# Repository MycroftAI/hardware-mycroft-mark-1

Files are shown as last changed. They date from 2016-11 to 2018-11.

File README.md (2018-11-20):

# hardware-mycroft-mark-1
*Open-sourcing our mechanical, electrical and industrial designs*

:sailboat: Note that this repository is a work-in-progress and will get better over time.

## Our open hardware principles
* **Copy our designs** – build your own Mycroft Mark 1 or its individual parts
* **Modify our designs** – remix is encouraged
* **Sell products based on our designs** – commercial use is permitted
* **Always keep the open license** – contribute your output back to the community
* **Credit the original author(s)** – like they do in science

## License
We're open-sourcing all our designs under the [CERN Open Hardware License](https://www.ohwr.org/licenses/cern-ohl/license_versions/v1.2), which is one of the open hardware licenses recommended by OSHWA, the Open Source Hardware Association. The release involves every single piece of our design except components we have no control over, like the Raspberry Pi. We've also joined the [Open Source Hardware Certification Program](http://www.oshwa.org/2016/10/07/announcing-the-oshwa-open-source-hardware-certification-program/).

OSHW

## Contact
If you are doing, or planning to do, something interesting with our designs, or if you just have a question regarding the files, get in touch with our Chief of Design Derick! (He was the one who designed Mycroft Mark 1’s enclosure.)

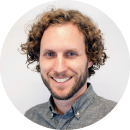
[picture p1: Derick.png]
Derick


**Derick Schweppe**  
Mycroft AI’s Chief of Design  
derick.schweppe@mycroft.ai

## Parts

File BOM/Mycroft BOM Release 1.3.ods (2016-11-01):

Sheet: Purchased Parts
Detailed list of off-the-shelf components in your product such as bateries, accessories, fasteners, etc.
Quantity | Part Number | Part Name | Description | Manufacturer | MPN | Unit Cost (USD) | Ext. Cost (USD)
1 | 3001 | Raspberry Pi 3 Model B | Raspberry Pi | Raspberry Pi Foundation | ??? | $33.750 | $33.750
1 | 3004 | hdmi cable-inside | 180-210 mm slim (3.5 mm outer diameter) male to panel mount female adpater | Vexos, see drawing: Mycroft 3004 HDMI male-female panel 1.11.pdf |  | $5.000 | $5.000
1 | 3009 | MicroSD Card (8gb) | SD card for software | Amazon |  | $2.430 | $2.430
1 | 3010 | Arduino Pro Mini 5v | Inland Arduino | Inland | 194126 | $4.000 | $4.000
1 | 3012 | Power Supply | 100-240VAC, 12.0VDC-15.0VDC, 18-24 Watts, UL approved | Mouser or equivalent with approval | 553-WSU120-1500 | $8.030 | $8.030
1 | 3013 | Speaker | HiWave BMR12 Compact 2" Full-Range Square Speaker 12W 8 Ohm | HiWave/Tectonic Elements (provided by Mycroft AI for first 1000 units) | 299-208 | $3.250 | $3.250
4 | 3002 | Housing Screws | m3x8mm thread forming screw | Stanley Delta PT M3x8mm | 96817A910 | $0.060 | $0.240
6 | 3003 | Speaker and Encoder Screws | m3x6mm thread forming screw | Stanley Delta PT M3x6mm | 96817A906 | $0.060 | $0.360
1 | 3005 | jst Mic Cable 1 | 180 mm 2 pin Female to Female JST XH connector cable 26 gauge | zhejiang leanhe electronics or equivalent with approval | ph-2y-180-ph-2y | $0.045 | $0.045
1 | 3006 | jst cable for front pcb | 180 mm 7 pin Female to Female JST XH connector cable 26 gauge | zhejiang leanhe electronics or equivalent with approval | xh-7y-180-xh-7y | $0.160 | $0.160
1 | 3008 | Rotary Encoder Cable | 200 mm 4 pin Female to Female JST XH Connector Cable 26 gauge | zhejiang leanhe electronics or equivalent with approval | xh-4y-180-xh-4y | $0.091 | $0.091
3 | 3011 | 18 mm standoffs | Raspberry Pi Standoffs | Essentra Components or equivalent with approval | RP914-ND | $0.179 | $0.537
1 | 3014 | speaker wire | 8.5" speaker wire with 2 pin JST XH connector and 22 gauge | zhejiang leanhe electronics or equivalent with approval | XH-2Y-200-free | $0.057 | $0.057
1 | 3016 | RCA mounting screw | #4 x 3/8 coarse thread plastic screw | Mcmaster-Carr | 97349A100 | $0.053 | $0.053
2 | 3017 | hdmi panel screws | M3x6mm thread forming screw | Stanley Delta PT M3x6mm | 91735A104 | $0.050 | $0.100
1 | 3018 | Serial Number and FCC label | label for Serial Number and FCC | Sticky Business |  | $0.230 | $0.230
1 | 3019 | ethernet cable |  | 6' ethernet cable |  | $0.500 | $0.500
1 | 3020 | rear 40 pin connector | 2.54mm PCB Socket Double Row Right Angle type | Dongguan Lanbo Electronics | PSRD254-40G-85 | $0.420 | $0.420
1 | 3021 | Raspberry Pi 40 pin connector | 2.54mm PCB Socket Double Row Female Header | Hello Electronics |  | $0.490 | $0.490
3 | 3022 | Arduino 12 pin Headers | 12 pin female connectors | Taojing Business (eBay purchase) |  | $0.020 | $0.060
1 |  | Freight |  |  |  | $6.000 | $6.000
 |  |  |  |  | TOTAL |  | $65.803

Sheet: Fabricated Parts
Detailed list of the custom fabricated parts in your product such as molded, stamped, diecast, etc.
Quantity | Part Number | Part Name | Description | Process Type | Material Type | Material Finish | Material Additives | Fixed Cost (USD) | Unit Cost (USD) | Ext. Cost (USD) | Notes
1 | 2001 | Housing Top | Housing Top | Injection Molding | ABS | bead blast | N/A | $20,000.000 | $2.200 | $2.200
1 | 2002 | Housing Bottom | Housing Bottom | Injection Molding | ABS | bead blast | N/A |  | $0.000 | $0.000
1 | 2003 | Expansion Plug R | Expansion Plug Right | Injection Molding | ABS | bead blast | N/A |  | $0.000 | $0.000
1 | 2004 | Expansion Plug L | Expansion Plug Left | Injection Molding | ABS | bead blast | N/A |  | $0.000 | $0.000
 | 2005 | knob | knob | Injection Molding | ABS | bead blast | N/A
1 | 2006 | Back Plate | Back Plate | Injection Molding | ABS | bead blast | N/A |  | $0.000 | $0.000
1 | 2007 | Front Plate | Front Plate | laser cutting | Acrylic / PMMA |  | N/A |  | $3.500 | $3.500
1 |  |  | Freight Injection molding |  |  |  |  |  | $0.500 | $0.500
1 |  |  | Freight Front Plate |  |  |  |  |  | $0.500 | $0.500
 |  |  |  |  |  |  |  |  | $0.000 | $0.000
 |  |  |  |  |  |  |  |  |  | $6.700

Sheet: PCBA
Detailed list of Bare Printed Circuit Boards onto which PCBA Components are added.
Quantity | Part Number | Part Name | Description | Material Type | Layer Count | Length (mm) | Width (mm) | Thickness (mm) | Min Trace Width | Min Trace Spacing | Min Device Pitch | Via Types | Mounting Types | Lead Time (wk) | MOQ | Fixed Cost (USD) | Unit Cost (USD) | Ext. Cost (USD) | Notes
1 | 1001 | Main_PCB | Main PCB | FR-4 | 2 |  |  | 1.60 | 6 mil | 6 mil |  | Through/Blind/Buried | SMT & THrough-Hole |  |  |  | $18.060 | $18.060
1 | 1002 | Front_PCB | Front PCB | FR-4 | 2 |  |  | 1.60 | 6 mil | 6 mil |  | Through/Blind/Buried | SMT & THrough-Hole |  |  |  | $18.460 | $18.460
1 | 1003 | Encoder_PCB | Encoder PCB | FR-4 | 2 |  |  | 1.60 | 6 mil | 6 mil |  | Through/Blind/Buried | SMT & THrough-Hole |  |  |  | $2.940 | $2.940
2 | 1004 | NeoPixel PCB | NeoPixel PCB | FR-4 | 2 |  |  | 1.60 | 6 mil | 6 mil |  | Through/Blind/Buried | SMT & THrough-Hole |  |  |  | $1.780 | $3.560
 |  |  |  |  |  |  |  |  |  |  |  |  |  |  |  |  |  | $0.000
 |  |  |  |  |  |  |  |  |  |  |  |  |  |  |  |  |  | $0.000
 |  |  |  |  |  |  |  |  |  |  |  |  |  |  |  | TOTAL | $43.020

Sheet: Packaging
Detailed list of all the elements of your product packaging.
Quantity | Part Number | Part Name | Description | Procurement Method | Lead Time (wk) | MOQ | Fixed Cost (USD) | Unit Cost (USD) | Ext. Cost (USD) | Notes
1 | PACK001 | Product Box | Printed Tablock Craft Cardboard Product Box 13"x10"x4" |  |  |  | $1,465.000 | $1.006 | $1.006
1 | PACK002 | Product Box Tape | Product Box Tape |  |  |  |  | $0.020 | $0.020
1 | PACK003 | Product Box Insert | folded cardboard tray |  |  |  |  | $1.000 | $1.000
1 | PACK004 | Product Bag | Protective Poly Bag |  |  |  |  | $0.200 | $0.200
1 | PACK005 | Quick Start Guide | Mulit-page Printed Manual |  |  |  |  | $1.000 | $1.000
1 | freight |  |  |  |  |  |  | $0.500 | $0.500
 |  |  |  |  |  |  |  | $0.000 | $0.000
 |  |  |  |  |  |  |  |  | $0.000
 |  |  |  |  |  |  |  |  | $0.000
 |  |  |  |  |  |  |  | $3.726 | $0.000
 |  |  |  |  |  |  |  |  | $0.000
 |  |  |  |  |  |  |  |  | $0.000
 |  | $1.006 per box for 1000 quantity |  |  |  |  |  |  | $0.000
 |  |  |  |  |  |  |  |  | $0.000
 |  | Fixed cost:
 |  | Die Cost: $854.00
 |  | Print Plate: $611.00

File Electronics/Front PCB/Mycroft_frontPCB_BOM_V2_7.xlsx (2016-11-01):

Description | Schem Ref | Qty | MFG Part # | Digikey # | x
0.1uf 0805 Captiro | FrontPCB C1, C2, C3, C9 | 4 | CL21F104ZBCNNNC | 1276-1007-1-ND | x
100uf Cap | FrontPCB C4, C5 | 2 | EEE-1VA101XP | PCE3951CT-ND | x
10uf 1210 CAP | FrontPCB C6, C8 | 2 | GMK325F106ZH-T | 587-1391-1-ND | x
2.2uf 0805 Cap | FrontPCB C7, C15 | 2 | C2012X7R1C225K125AB | 445-1420-1-ND | x
10nf 0805 Cap | FrontPCB C10 | 1 | C2012C0G1H103J060AA | 445-7519-1-ND | x
22uf 1210 Cap | FrontPCB C11, C12 | 2 | EMK325F226ZN-T | 587-1390-1-ND | x
3.9nf 0805 Cap | FrontPCB C13 | 1 | C0805C392K5RACTU | 399-1154-1-ND | x
Inductor 15uh | FrontPCB L1 | 1 | VLF10045T-150M3R5 | 445-3579-1-ND | x
JST XH 7pin | FrontPCB J1 | 1 | B7B-XH-A(LF)(SN) | 455-2252-nd
JST PH 2pin-RA | FrontPCB J3 | 1 | S2B-PH-K-S(LF)(SN) | 455-1719-ND
Mic | FrontPCB MK1 | 1 | CMA-4544PF-W | 102-1721-ND | x
220 ohm 0805 Resistor | FrontPCB R1-R16, R21-R36 | 32 | ERJ-6GEYJ221V | P220ACT-ND | x
10k 0805 Resistor | FrontPCB R18 | 1 | ERJ-6GEYJ103V | P10KACT-ND | x
100k 0805 Resistor | Frontpcb R17 | 1 | RC0805FR-07100KL | 311-100KCRCT-ND | x
45.3k 0805 Resistor | FronPCB R19 | 1 | ERJ-6ENF4532V | P45.3KCCT-ND | x
13k 0805 Resistor | FrontPCB R20 | 1 | ERJ-6GEYJ133V | P13KACT-ND | x
TSOP6238TR | FrontPCB U12 | 1 | TSOP6238TR | TSOP6238CT-ND | x
RT-8250 | FrontPCB U14 | 1 | RT8250GSP | 1028-1002-1-ND | x
AP2114 | FrontPCB U16 | 1 | AP2114H-3.3TRG1 | AP2114H-3.3TRG1DICT-ND | x
HT1632c | Front PCB U1 | 1 | HT1632c | NA | x
LED Matrix-GYX Optoelectronics | Front PCB U2, U3, U4, U5 | 4 | GYXM-788CW | NA | x

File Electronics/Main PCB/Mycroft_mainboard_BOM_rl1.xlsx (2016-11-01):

Description | Schem Ref | Qty per board | MFG Part # | Digikey #
18pf 0805 Cap | MB C1, C2, C7, C44, C45, C46, C47 | 7 | CL21C180JBANNNC | 1276-1107-1-ND
330uf Cap | MB C3, C4 | 2 | UWT1C331MNL1GS | 493-2180-1-ND
1nf 0805 Cap | MB C32, C37, C38, C39 | 4 | C2012X7R2E102K085AA | 445-2277-1-ND
10uf Cap | MB C6, C10, C11, C40 | 4 | T491A106K010AT | 399-3684-1-ND
100nf Cap 0805 | MB C8, C9, C12, C13 | 4 | CL21F104ZBCNNNC | 1276-1007-1-ND
0.1uf 0805 Cap | MB C14, C15, C16, C21, C31, C36, C48, C52, C53 | 9 | CL21F104ZBCNNNC | 1276-1007-1-ND
100uf Cap | MB C17, C18, C30, C35 | 4 | EEE-1VA101XP | PCE3951CT-ND
10uf 25v 1210 Cap | MB C19, C20 | 2 | GMK325F106ZH-T | 587-1391-1-ND
10nf 0805 Cap | MB C22, C54 | 2 | C2012C0G1H103J060AA | 445-7519-1-ND
22uf 1210 Cap | MB C23, C24, C55 | 3 | CL32A226KAJNNNE | 1276-1101-2-ND
3.9nf | MB C25 | 1 | C0805C392K5RACTU | 399-1154-1-ND
1uf 35v 0805 | MB C26, C27, C28, C29, C41 | 5 | C2012X5R1V105K085AB | 445-14415-1-ND
0.47uf 0805 | MB C33, C34, C51 | 3 | C0805C474K5RACTU | 399-8100-1-ND
10uf Can cap | MB C42, C43 | 2 | EEE-1EA100WR | PCE3895CT-ND
10uf 0805 Cap CER | MB C5 | 1 | CL21A106KPCLQNC | 1276-2402-1-ND
Polyfuse .5A 6v | MB F1 | 1 | 1206L050YR | F2112CT-ND
Polyfuse 8v 1.1a 1206 | MB F2 | 1 | 1206L110THYR | F3371CT-ND
Polyfuse 16v .25A 1206 | MB F3 | 1 | 1206L025YR | F2110CT-ND
FUSE PTC 0.75A 8V 1210 | MB F4 | 1 | 0ZCB0075FF2G | 507-1490-1-ND
FUSE PTC 1.5A 24V | MB F5 | 1 | MF-MSMF150/24X-2 | MF-MSMF150/24X-2CT-ND
Jst 7pin XH connector | MB J2 | 1 | B7B-XH-A(LF)(SN) | 455-2252-ND
Jst 4 pin xH connector | MB j3 | 1 | B4B-XH-A(LF)(SN) | 455-2249-ND
Rpi 2x20 connector | MB J4 | 1
2x20 output conenction | MB J6 | 1
10uf Inductor | MB L1 | 1 | NR4018T100M | 587-1664-1-ND
Ferrite bead | MB L2, L3, L6 | 3 | HI1812V101R-10 | 240-2543-1-ND
100 ohm resistor 0805 | MB R1, R2, R3, R30, R31, R32, R33, R36,R40, R41, R42, R43, | 14 | RC0805FR-07100RL | 311-100CRCT-ND
1k Resistor 0805 | MB R4, R5, R16, R9, R34, R35, R38, R39 | 8 | RC0805JR-071KL | 311-1.0KARCT-ND
47k Resistor 0805 | MB R6, R7, R10, R24, R25 | 5 | RMCF0805FT47K0 | RMCF0805FT47K0CT-ND
24k ohm 0805 Resistor | MB R8, | 1 | RC0805JR-0724KL | 311-24KARCT-ND
10 ohm 1206 Resistor | MB R11 | 1 | ERJ-8ENF10R0V | P10.0FCT-ND
100k 0805 Resistor | MB R12, R13, R17, R37, R46 | 5 | RC0805FR-07100KL | 311-100KCRCT-ND
10k 0805 Resistor | MB R14, R15, R18, R21, R26, R27 | 6 | ERJ-6GEYJ103V | P10KACT-ND
45.3k Resistor 0805 | MB R19 | 1 | ERJ-6ENF4532V | P45.3KCCT-ND
13k 0805 Resistor | MB R20 | 1 | ERJ-6GEYJ133V | P13KACT-ND
100 ohm 0805 Resistor | MB R22, R23 | 2 | ERJ-P06J101V | P100ADCT-ND
WM8731 Interface | MB U1 | 1 | WM8731SEDS/RV | WM8731SEDS/RVCT-ND
Tpa3113 | MB U2 | 1 | TPA3113D2PWPR | 296-25122-1-ND
2.1mm DC Jack | MB U12 | 1 | PJ-002A | CP-002A-ND
RCA Stereo Jack | MB U13 | 1 | RCJ-2123 | CP-1432-ND
RT-8250 | MB U14 | 1 | RT8250GSP | 1028-1002-1-ND
TXB0104 | MB U15, U28 | 2 | TXB0104DR | 296-21928-2-ND
12.288mhz crystal | MB Y1 | 1 | ABLS-12.288MHZ-B4-T | 535-10219-2-ND
Reverse polarity diode | MB D1 | 1 | PMEG4050EP,115 | 568-7408-1-ND
N channel fet level shift | MB Q1 | 1 | BSS138 | BSS138CT-ND
JST XH Speaker Con | MB J7 | 1 | B2B-XH-A(LF)(SN) | 455-2247-ND
inductor | MB L10 | 1 | VLF10045T-150M3R5 | 445-3579-1-ND
2.2uf 0805 capacitor | MB C49, C50 | 2 | LMK212B7225KG-T | 587-1286-1-ND
JST PH 2 pin | MB J8 | 1 | B2B-PH-K-S(LF)(SN) | 455-1704-ND
26 ohm ferrite bead 0603 | MB L4, L5 | 2 | BLM18KG260TN1D | 490-5252-1-ND
150k 0805 resistor | MB R44 | 1 | RMCF0805JT150K | RMCF0805JT150KCT-ND
2.2k 0805 resistor | MB R45 | 1 | RC0805JR-072K2L | 311-2.2KARCT-ND
Max9814 | MB U3 | 1 | MAX9814ETD+T | MAX9814ETD+TCT-ND
0805 Ferrite | L7, L8, L9 | 3 | 742792023 | 732-1613-1-ND

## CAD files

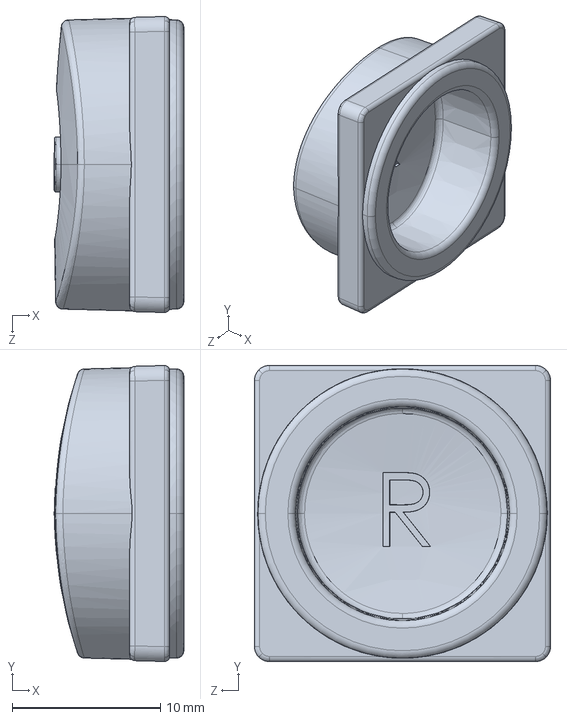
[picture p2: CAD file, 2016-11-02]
Plastics/3D print/expansion port right 1.21.STEP
8.75 x 20.0 x 20.0 mm

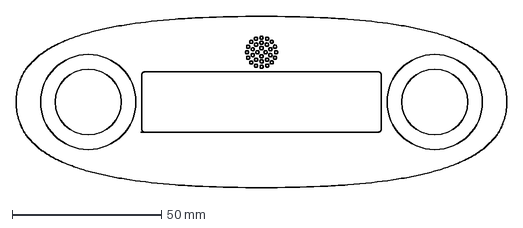
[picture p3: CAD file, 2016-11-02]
Plastics/Laser cut/Mycroft front plate cutting lines 1.21.dxf
164.4 x 57.4 mm

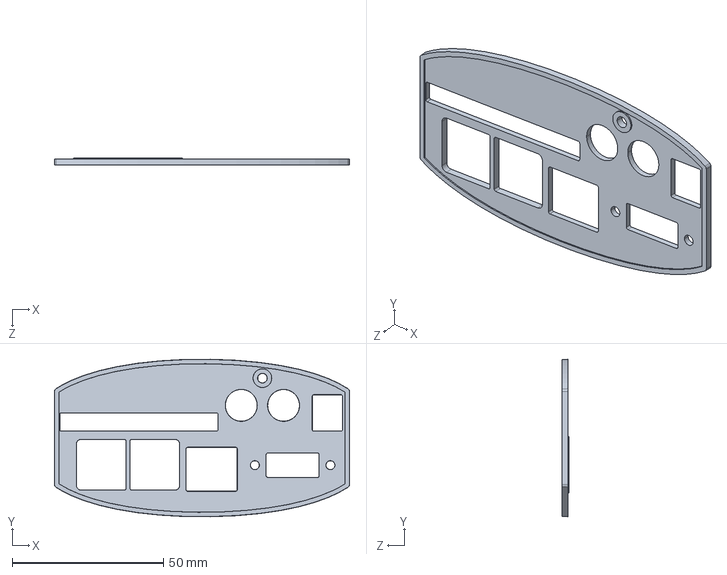
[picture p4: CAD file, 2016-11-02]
Plastics/3D print/back plate 1.21.STEP
97.6 x 52.1 x 2.40 mm

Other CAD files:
Plastics/3D print/expansion port left 1.21.STEP
Plastics/3D print/back plate 1.21.STL
Plastics/3D print/expansion port left 1.21.STL
Plastics/3D print/expansion port right 1.21.STL

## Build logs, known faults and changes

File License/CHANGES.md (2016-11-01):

Here we are compiling a community changelog. 

If you come up with a modification of our designs, please share it 
with the community, log your changes below, and upload the files to
our GitHub repository.

#Format

**Your name**  
*Date*  
Description of modification  

#Example

* older entry

* **David Smehlik**   
*12/31/2032*  
I used the original board design (electronics), but changed the 3D 
printed enclosure so Mark 1 has 3 feet instead of 4, and the face
and back plates are completely transparent. I created a pull request 
on GitHub with the modified files.

* newer entry

#Changelog

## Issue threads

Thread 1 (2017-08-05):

Use normal screws

singpolyma, 2017-08-05:
For future designs, consider using screws that users are likely to have a screwdriver for.

akuataja, 2018-04-23:
The team went back and forth on this. We eventually decided on Torx due to its advantages over the Phillips screws, some of which are mentioned [here](https://en.wikipedia.org/wiki/Torx#Principles_of_operation). As for the tool availability, I am told we include a Torx wrench in Mark I boxes. If you didn't get it in yours, send me a message, and I'll sort it out!

singpolyma, 2018-04-23:
I certainly didn't receive a driver with mine. Ended up buying a torx set (two, actually, first one wasn't long enough) so I could repair my Mark I

AFAICT torx screws are basically low-grade physical DRM equivalent for hardware

penrods, 2018-04-23:
The feedback is definitely appreciated.  As you noted, the depth/narrowness of the channel was also a challenge -- I own Torx drivers, but they were too wide to fit.  Torx do have some legit advantages -- I've never stripped out a Torx screw -- but they are not nearly as common.

As David mentioned, including a Torx driver is now done by default.  Once we realized this was an issue for many people we started including a "screwdriver" similar to what you get with Ikea furniture in the boxes.  We are happy to send one if you'd like, but for most of the early batches who have contacted us it is faster/easier to hit a local store rather than wait.

Sorry about the hassle, we are learning as we go on this!

kalon33, 2018-07-21:
@singpolyma same thing here, I didn't received a Torx wrench in my Mark I box and had to buy one today as my Mycroft won't boot and I had to try a microSD image restoring...

tiredoftry, 2018-09-11:
Looking for a driver for my screws as well.  It would be nice if the SD card was accessible without taking the Mark I apart.  Hopefully, this will be a feature on the Mark II.

ruth-connect, 2020-06-08:
Do you know what size Torx screwdriver you need for opening the Mark I please? The smallest screwdriver I have currently is a T15 - and that is too big.

Closed 2018-04-23.

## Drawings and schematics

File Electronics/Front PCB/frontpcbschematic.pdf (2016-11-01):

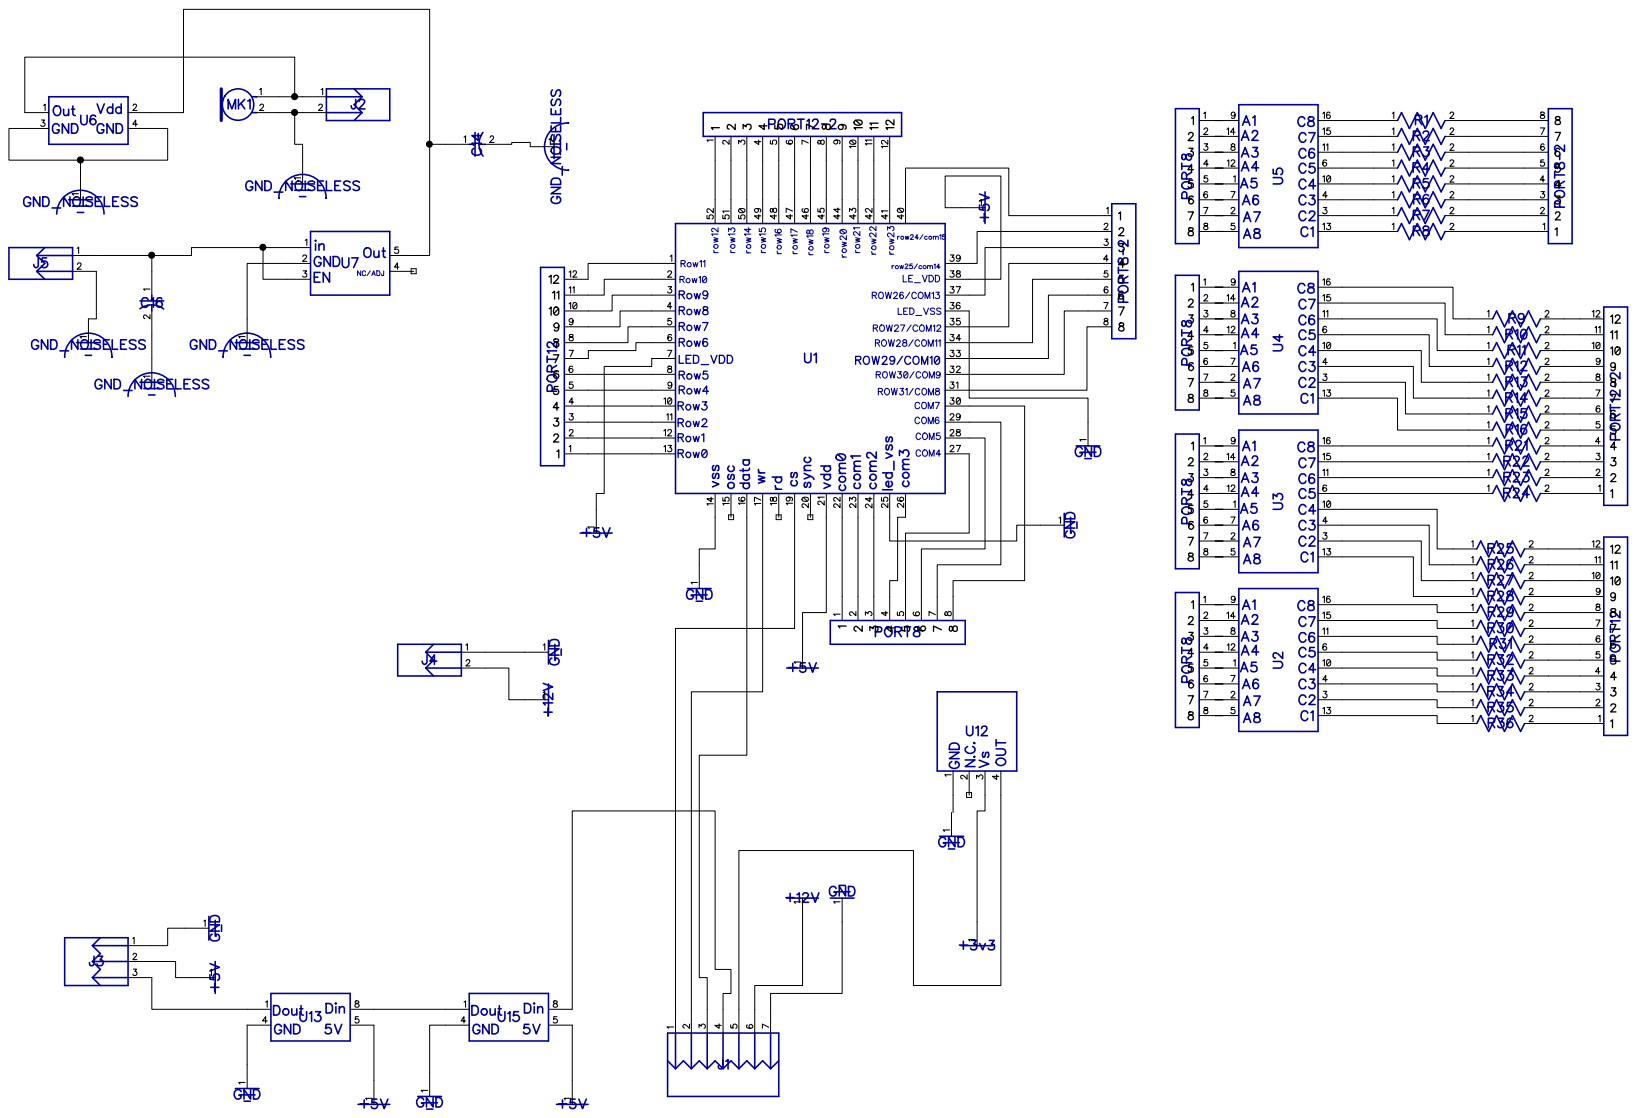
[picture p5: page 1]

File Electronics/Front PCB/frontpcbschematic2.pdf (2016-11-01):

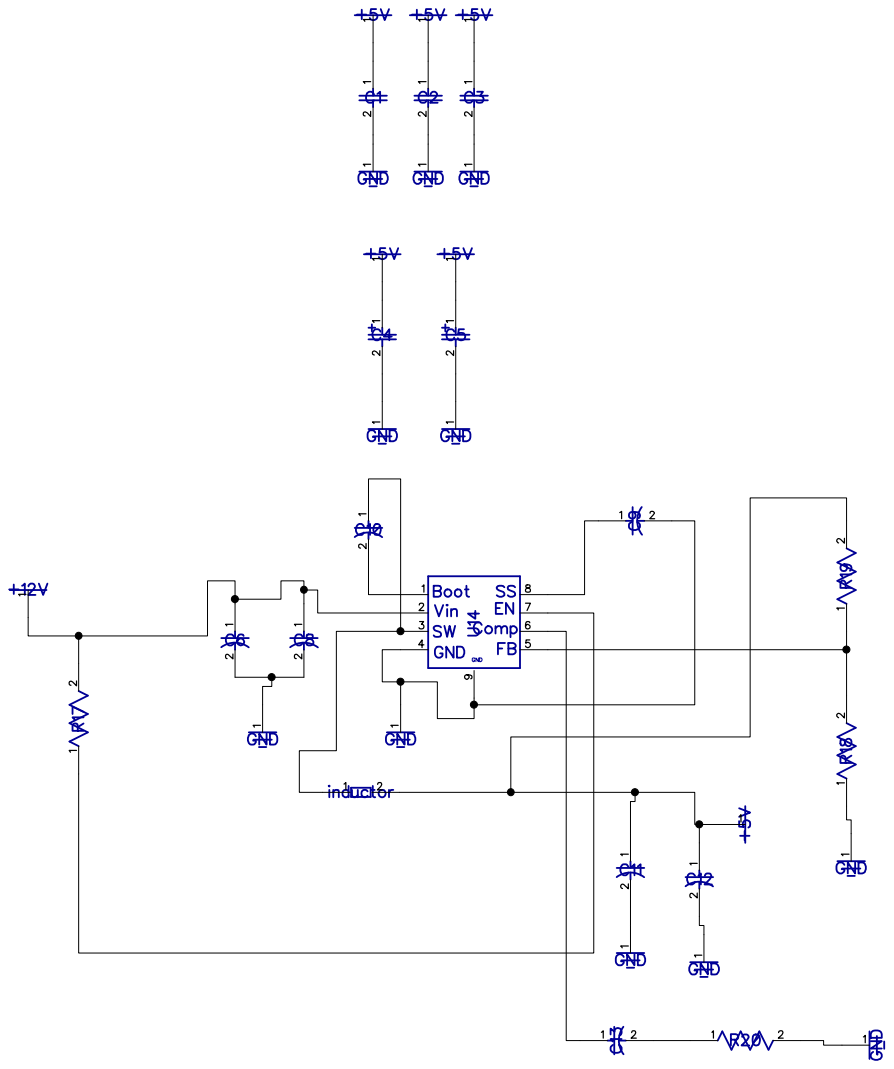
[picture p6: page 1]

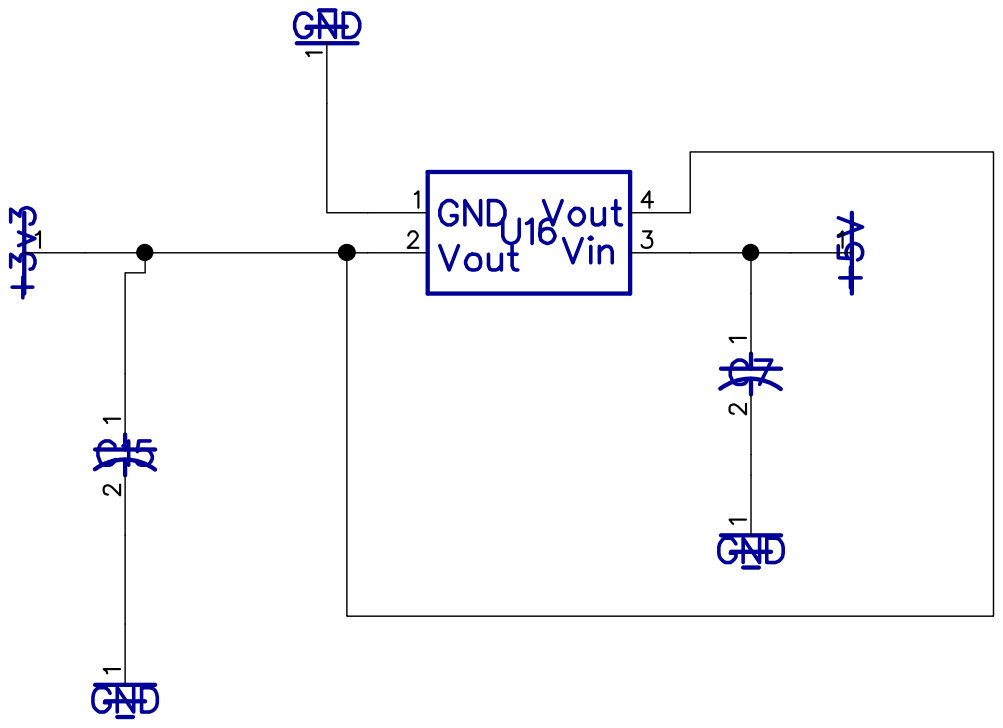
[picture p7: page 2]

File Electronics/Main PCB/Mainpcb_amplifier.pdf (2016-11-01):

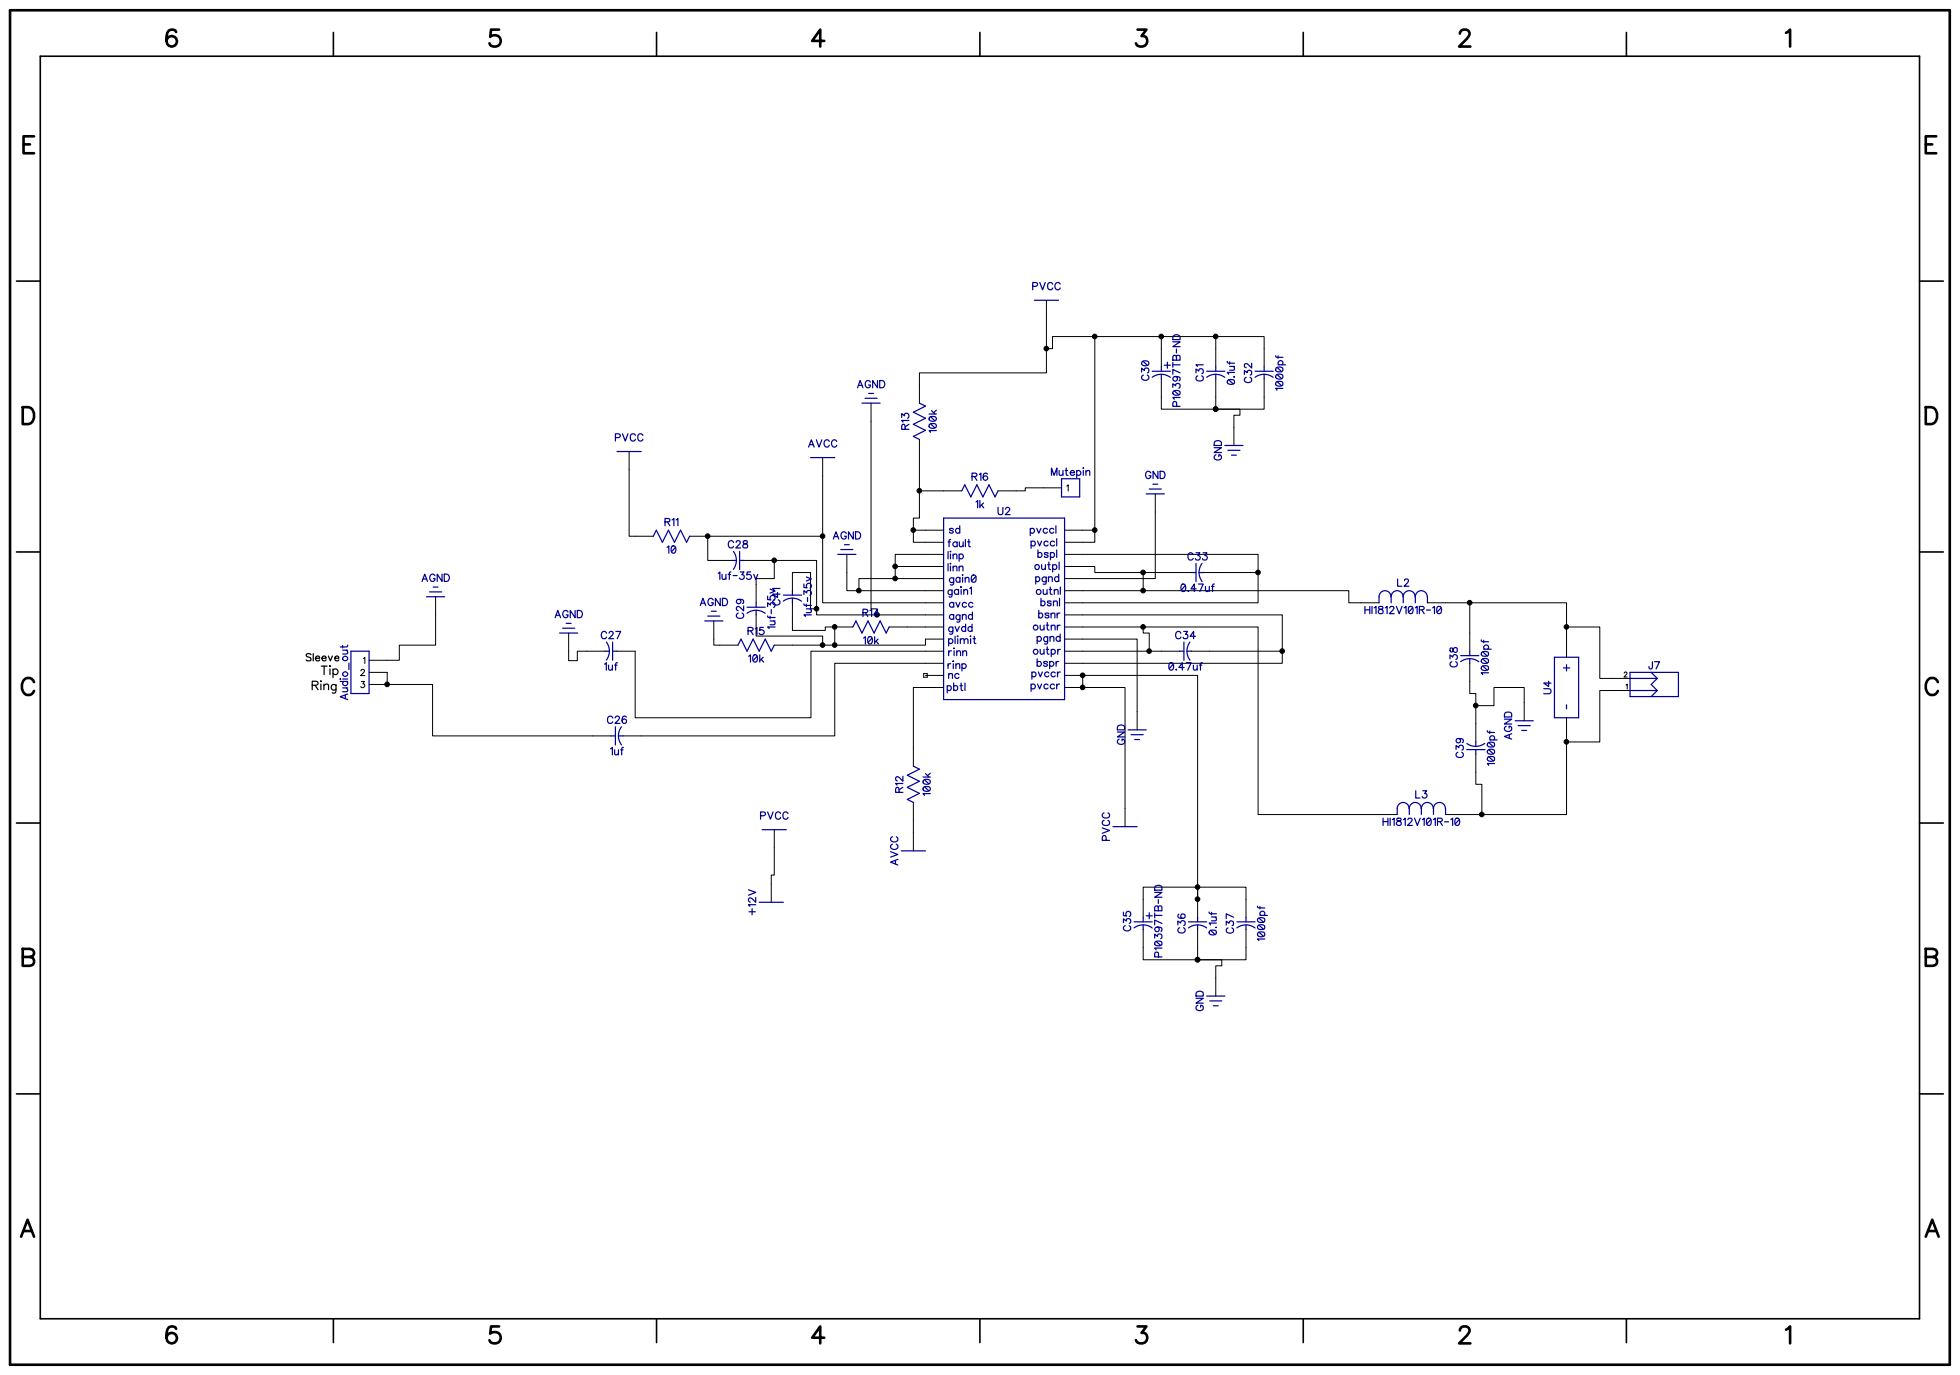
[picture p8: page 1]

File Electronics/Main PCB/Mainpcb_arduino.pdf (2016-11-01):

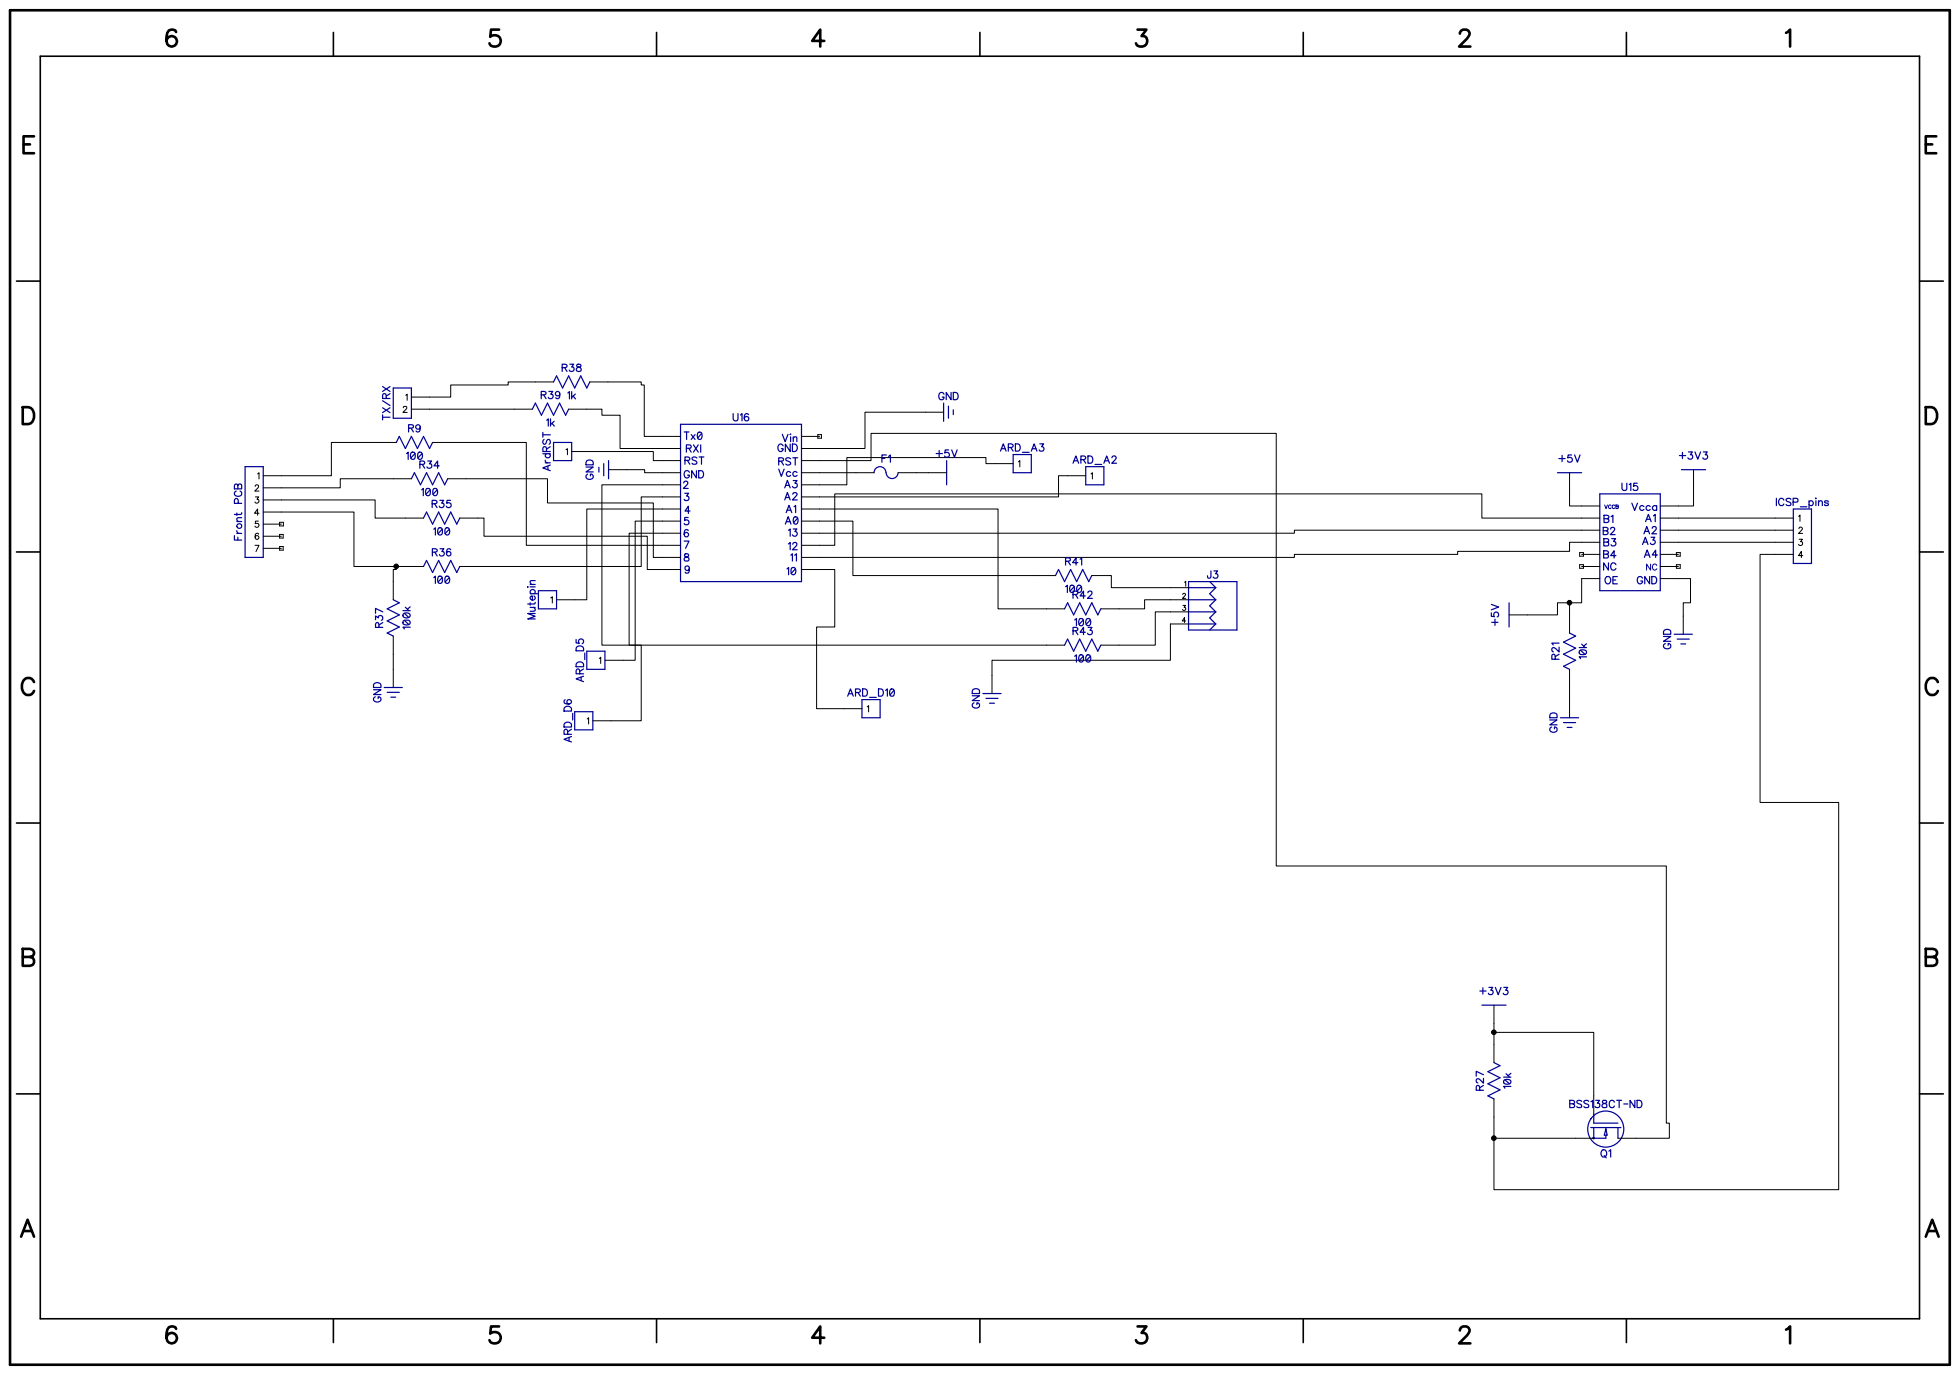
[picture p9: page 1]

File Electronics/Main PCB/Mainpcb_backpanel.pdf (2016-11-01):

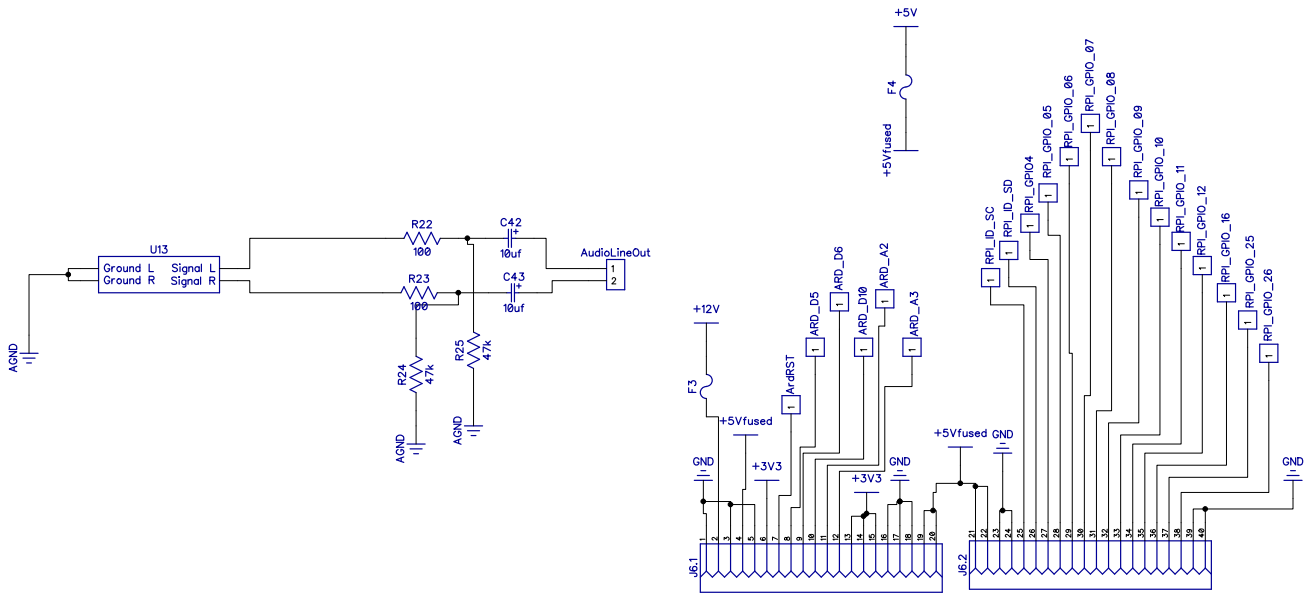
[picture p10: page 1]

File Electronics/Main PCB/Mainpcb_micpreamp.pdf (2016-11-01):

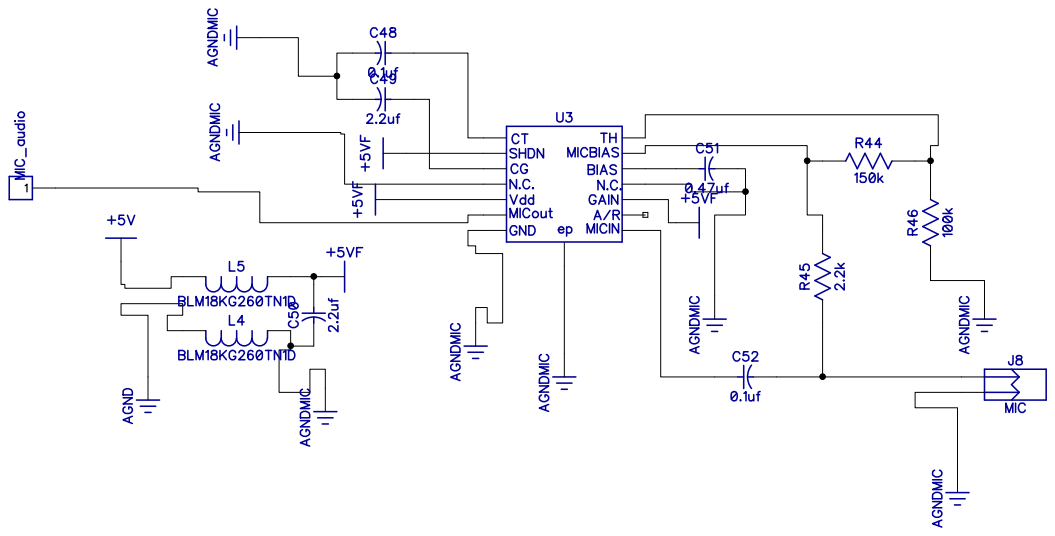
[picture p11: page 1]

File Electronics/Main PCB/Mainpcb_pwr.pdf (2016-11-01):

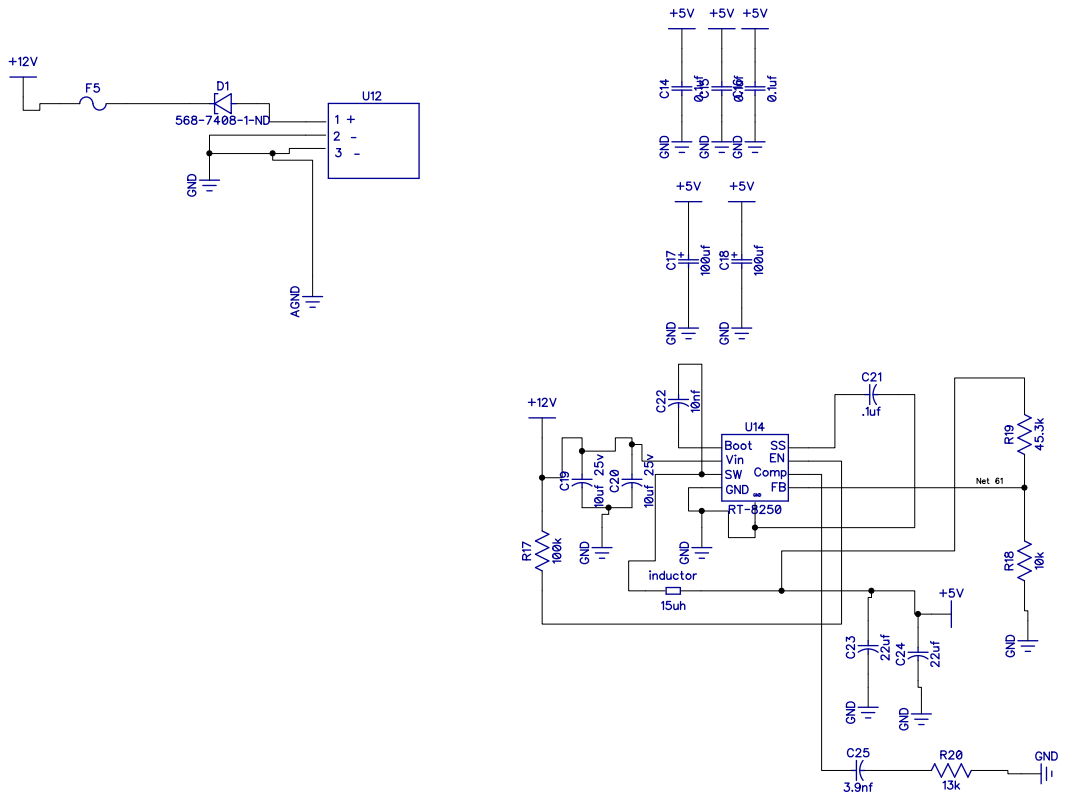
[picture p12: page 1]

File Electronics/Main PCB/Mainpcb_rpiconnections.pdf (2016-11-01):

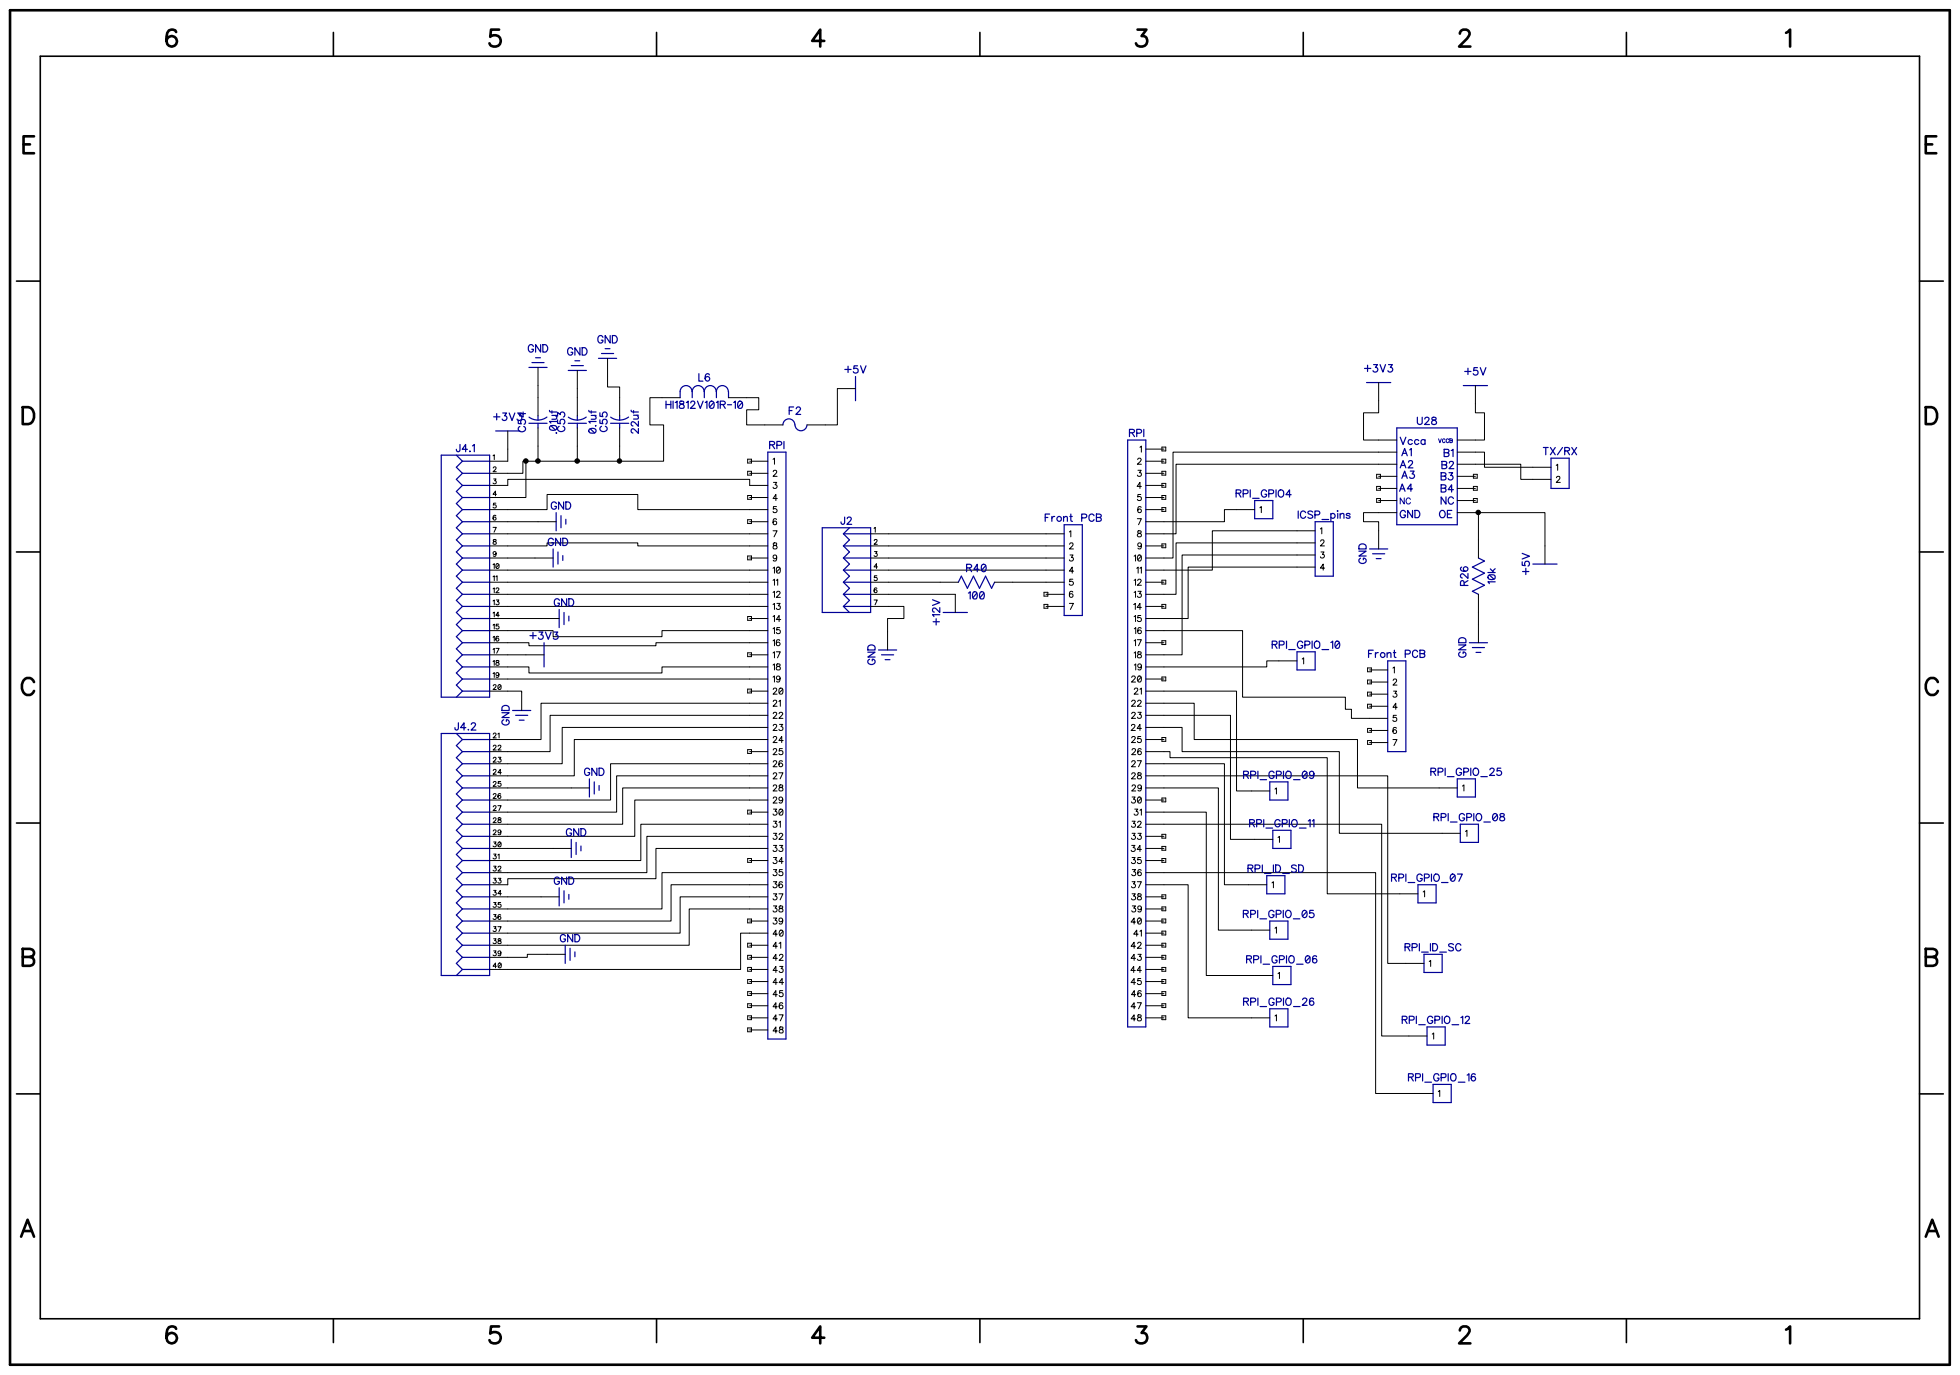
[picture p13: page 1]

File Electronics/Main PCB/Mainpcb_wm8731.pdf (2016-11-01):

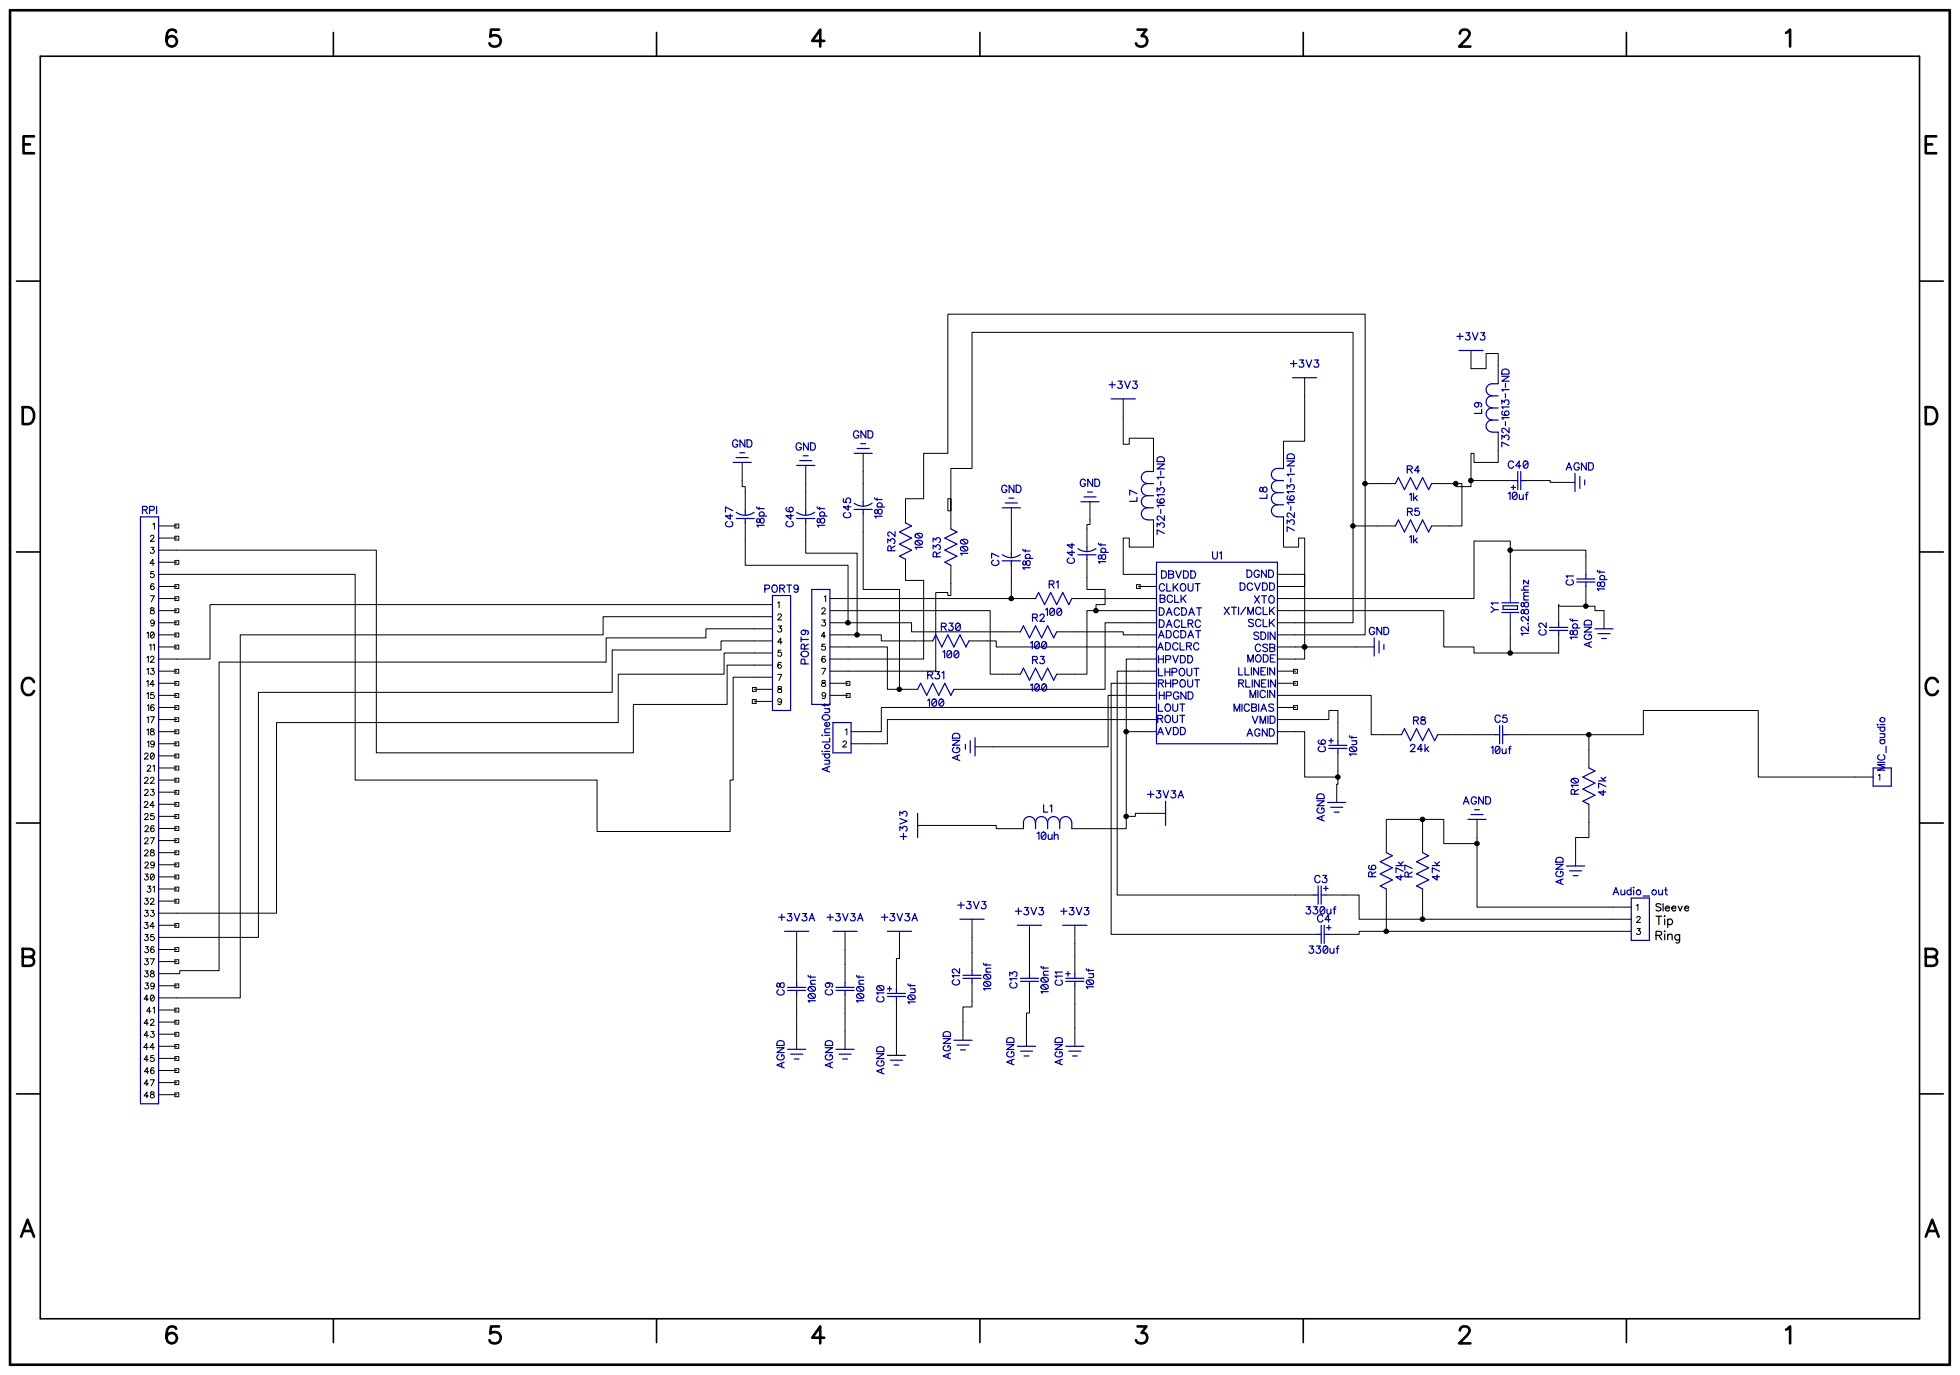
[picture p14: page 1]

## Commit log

2016-11-01 Initial upload of design files and license
    [Mycroft BOM Release 1.3.ods, Mycroft_frontPCB_BOM_V2_7.xlsx, Mycroft_mainboard_BOM_rl1.xlsx]
2016-11-02 added 3d print and laser cut files
    [Mycroft front plate cutting lines 1.21.dxf, back plate 1.21.STEP, back plate 1.21.STL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]
